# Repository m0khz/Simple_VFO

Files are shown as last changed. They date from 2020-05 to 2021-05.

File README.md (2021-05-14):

# Simple_VFO
Simple VFO using Si5351 &amp; custom hardware.

A comprehensive video build of this project is available here:

https://youtu.be/oWSVf3w8YGg

The 2.2" tft module uses the ILI9341 driver there are different versions out there and the pinout changes,

 *                            - the boards have been designed for this type:
 *                            - https://www.elektor.com/2-2-spi-tft-display-module-240x320 
 *                            - I bought mine from eBay

The Teensy 3.2 module available from https://www.pjrc.com/store/teensy32.html 

 *                            - I bought mine from eBay

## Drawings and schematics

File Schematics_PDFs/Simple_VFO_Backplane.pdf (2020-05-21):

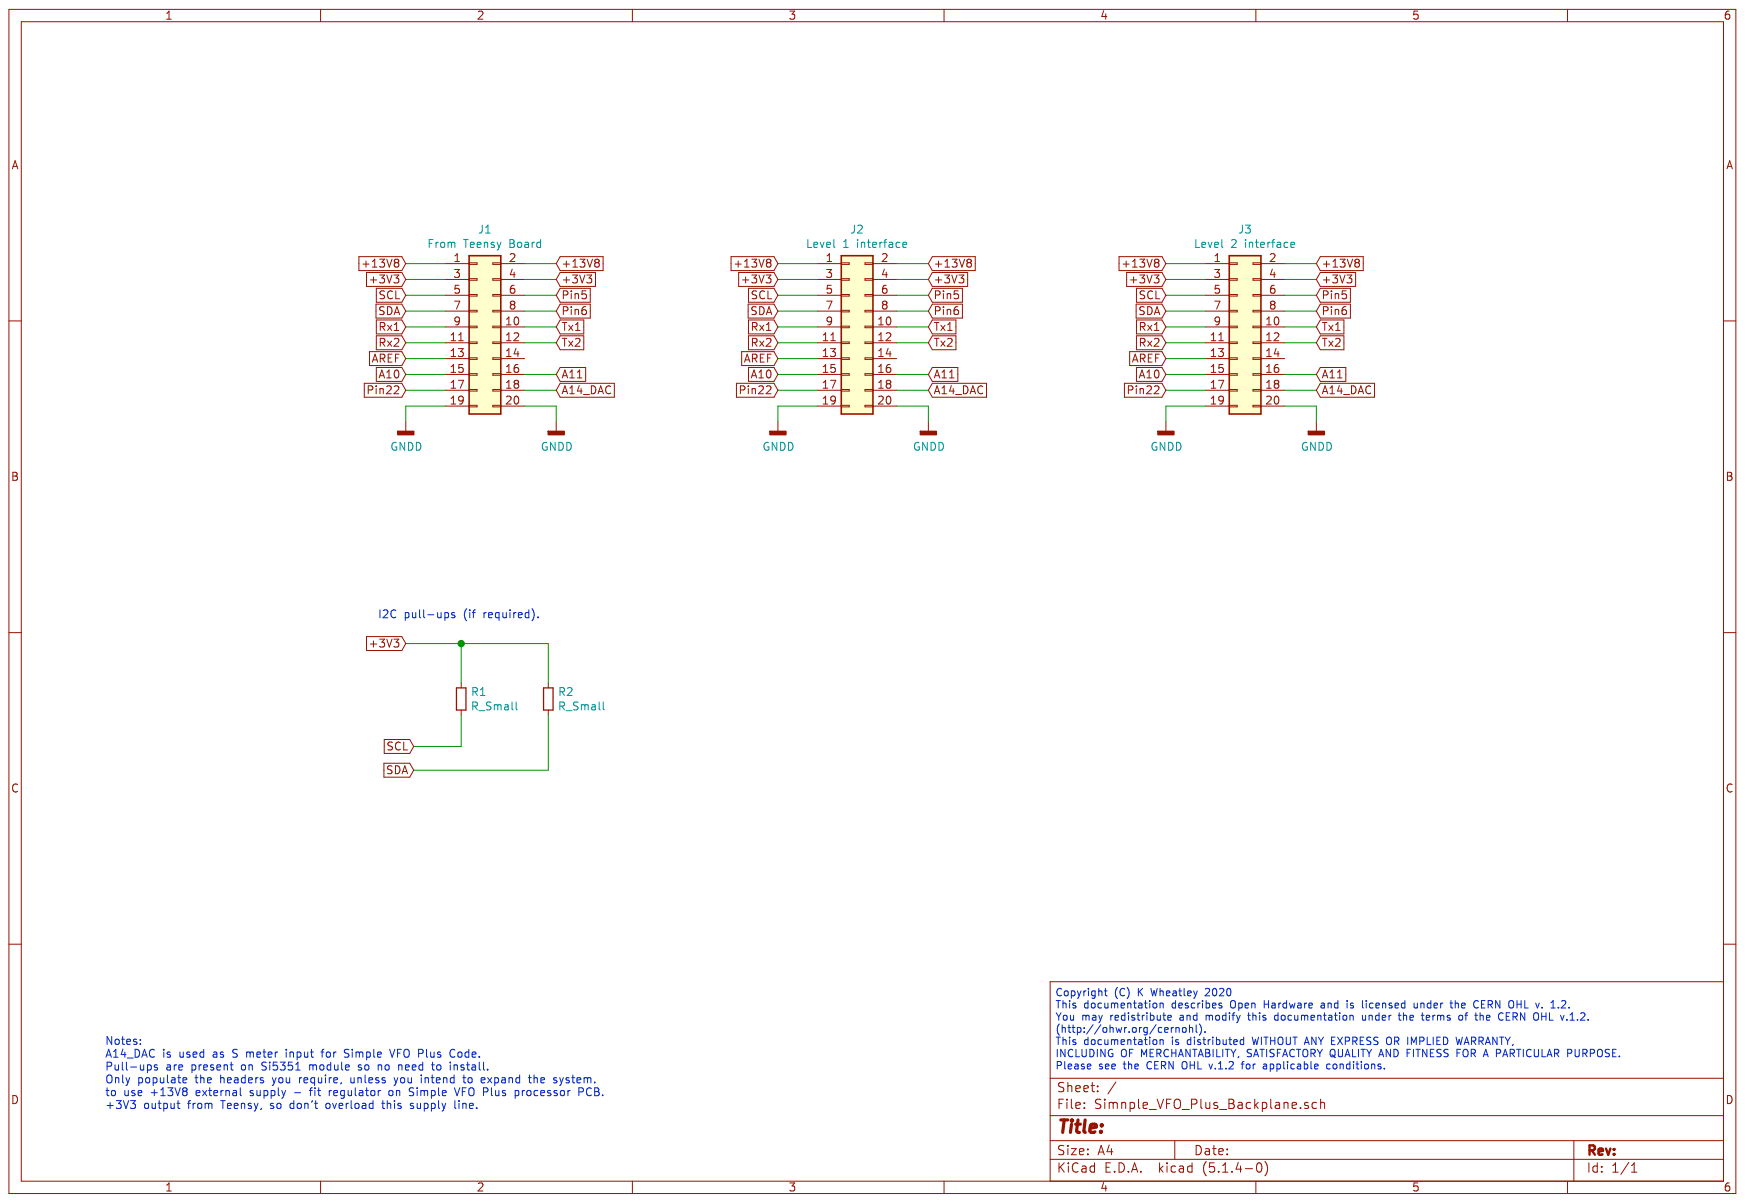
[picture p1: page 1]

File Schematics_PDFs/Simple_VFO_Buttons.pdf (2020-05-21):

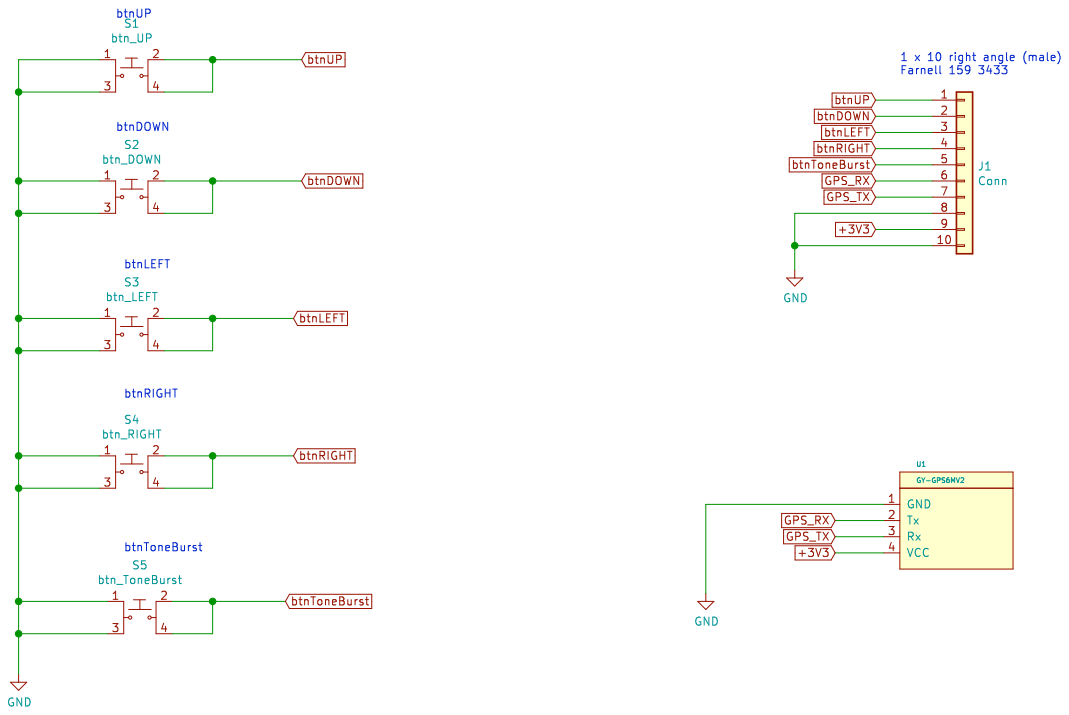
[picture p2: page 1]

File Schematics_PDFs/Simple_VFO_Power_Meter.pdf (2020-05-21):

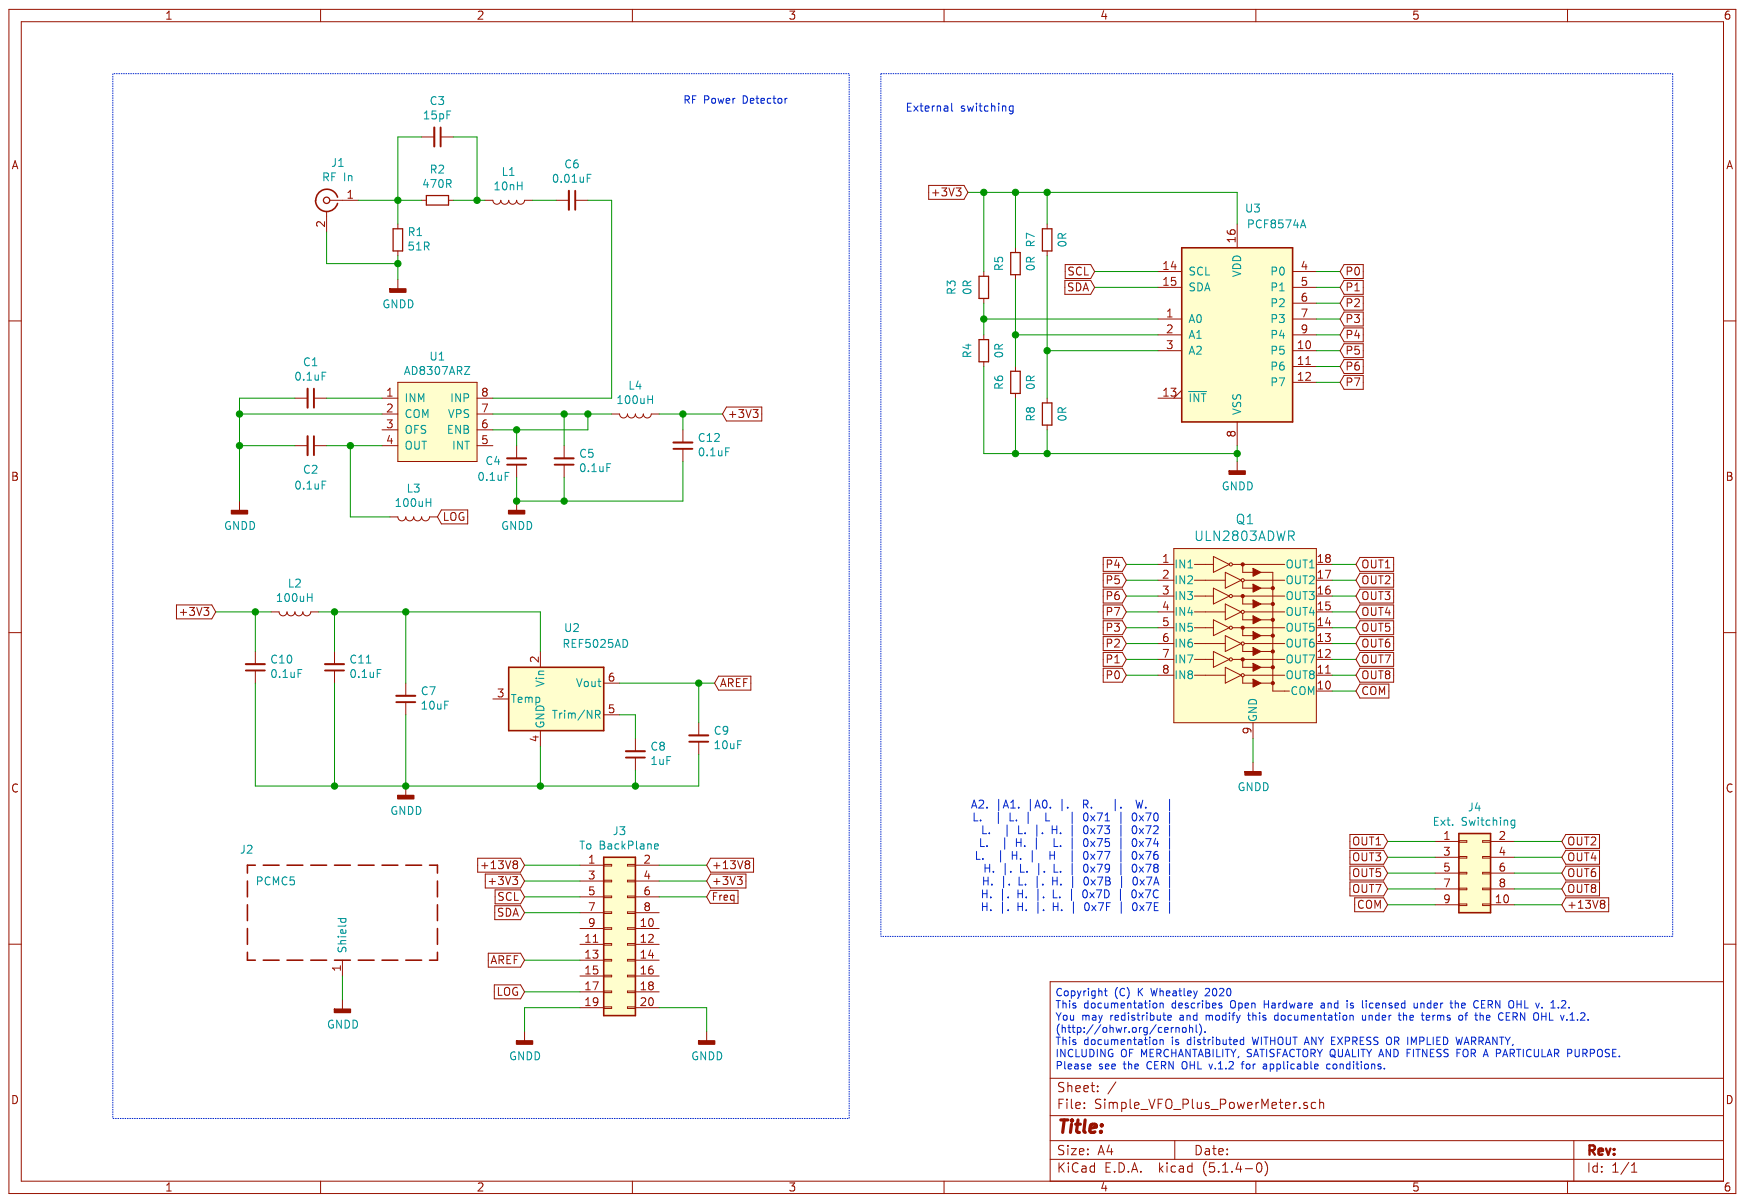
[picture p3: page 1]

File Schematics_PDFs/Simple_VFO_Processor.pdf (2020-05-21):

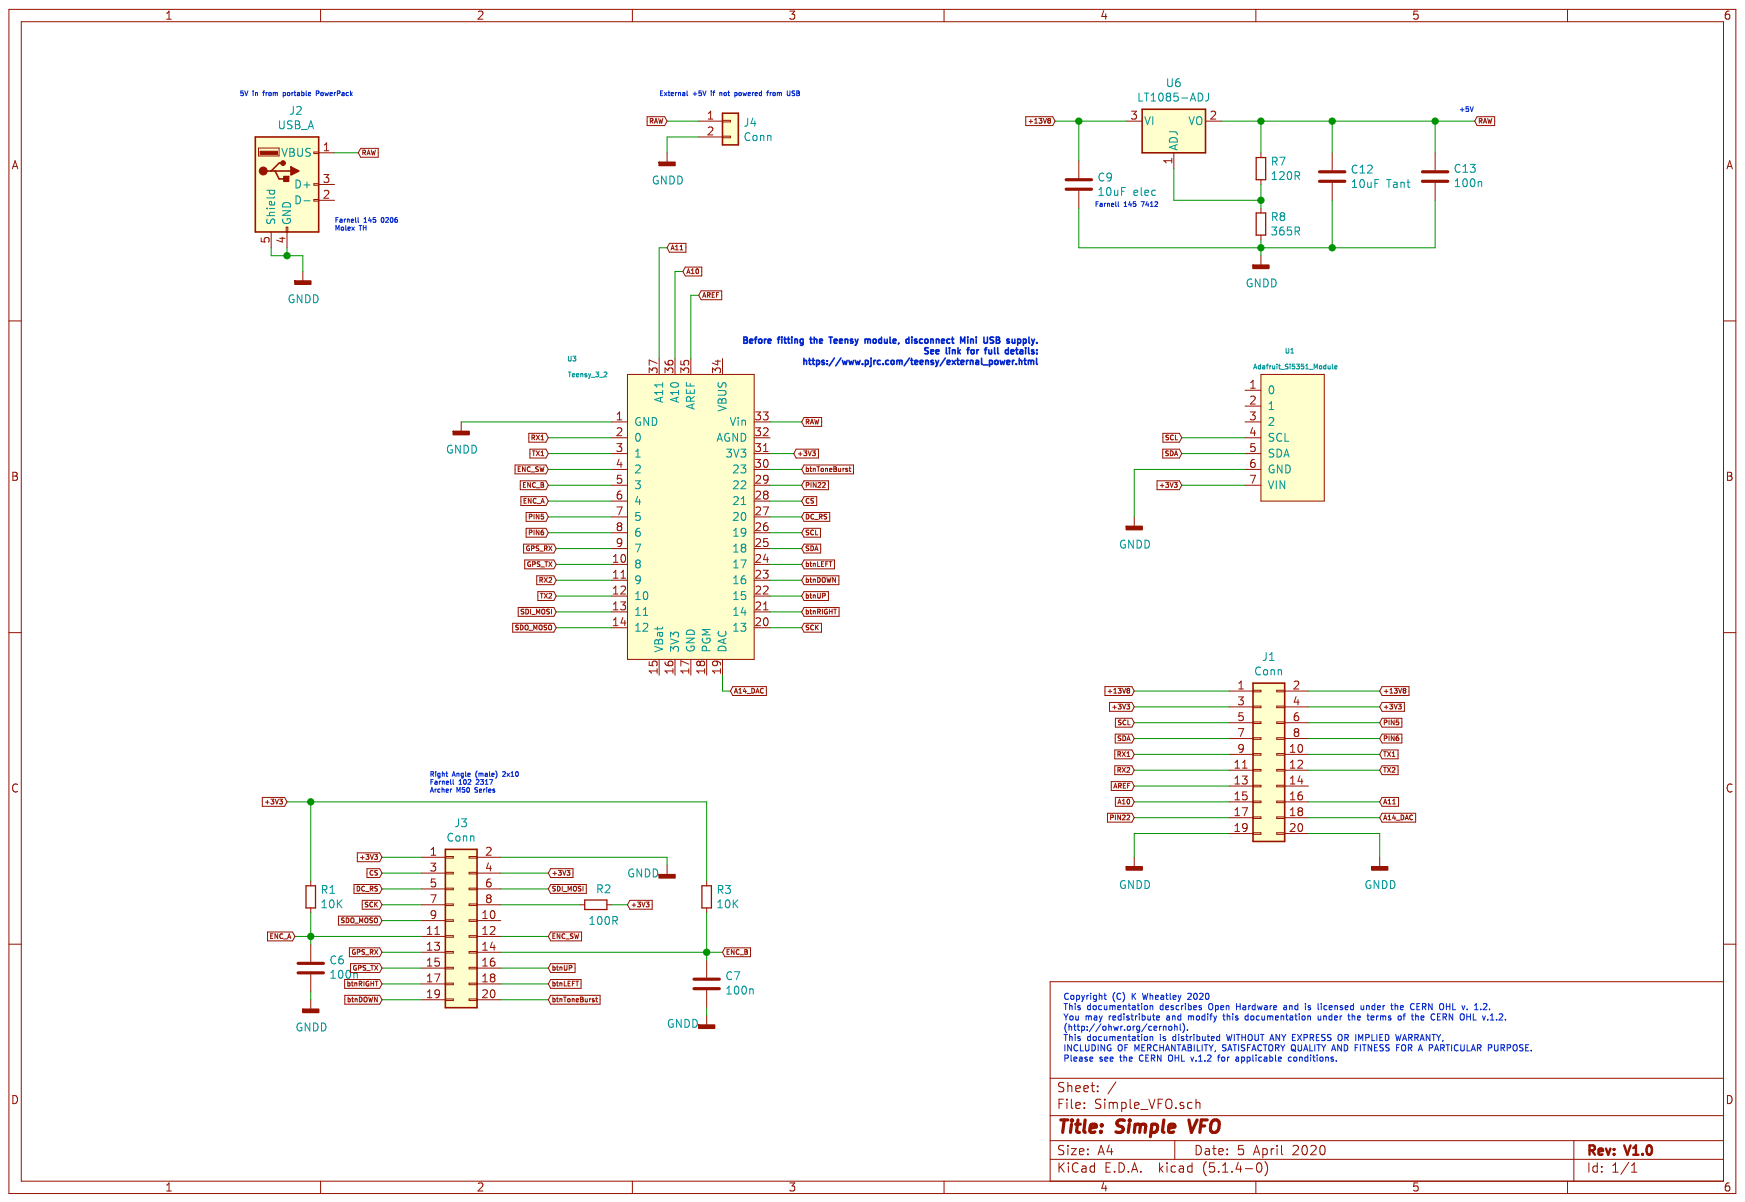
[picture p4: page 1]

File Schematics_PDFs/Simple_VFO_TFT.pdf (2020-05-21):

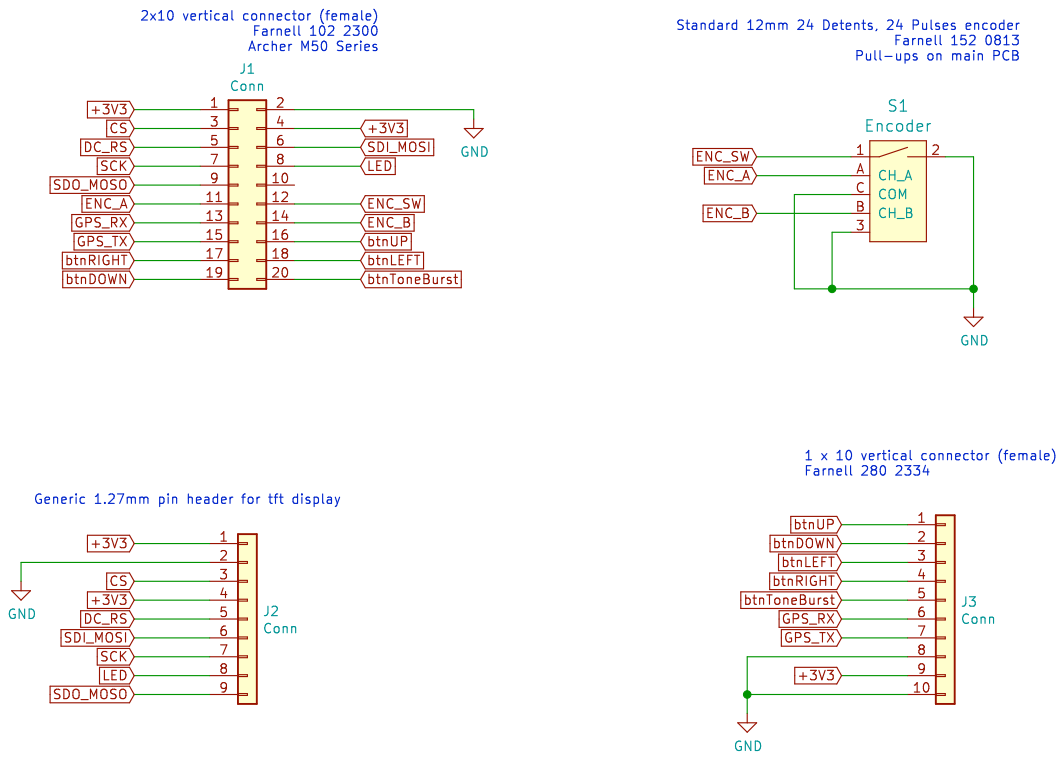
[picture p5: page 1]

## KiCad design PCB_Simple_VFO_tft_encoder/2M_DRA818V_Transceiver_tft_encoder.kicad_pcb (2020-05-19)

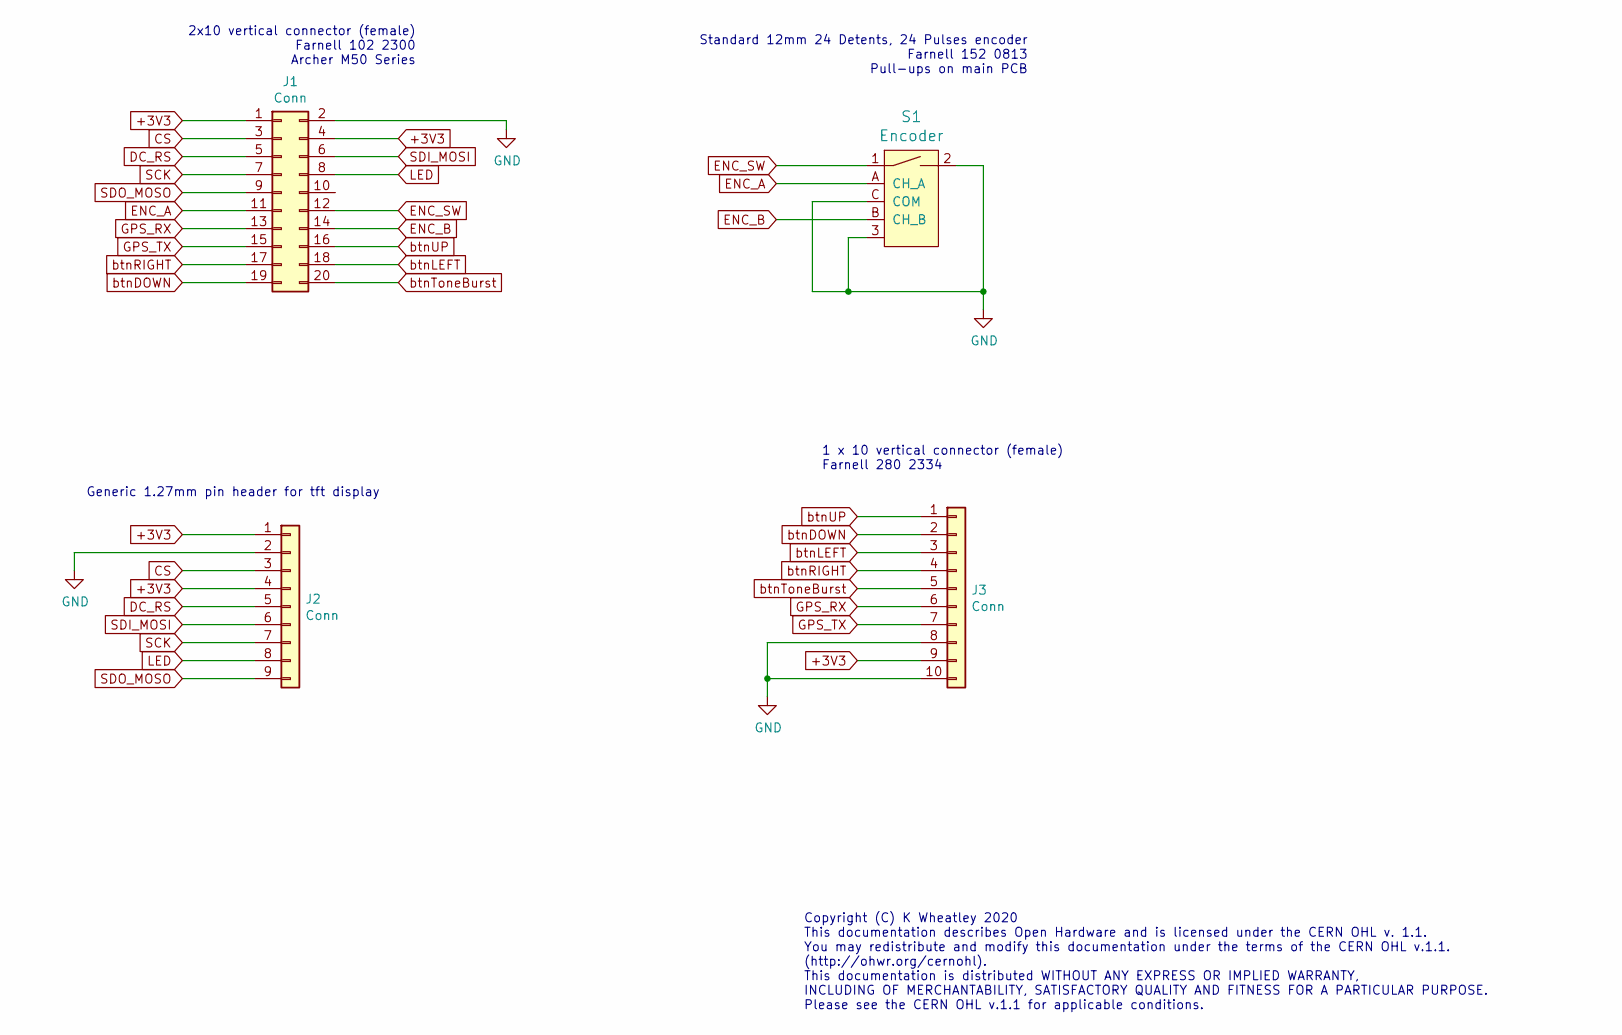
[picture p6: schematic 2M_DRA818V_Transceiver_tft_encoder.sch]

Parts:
J1: Conn; PinHeader_2x10_P2.54mm_Vertical
J2: Conn; PinHeader_1x09_P2.54mm_Vertical
J3: Conn; PinHeader_1x10_P2.54mm_Vertical
S1: Encoder; Rotary_Encoder_Switched_PEC11R; MPN PEC11R-4215F-S0024; Digi-Key_PN PEC11R-4215F-S0024-ND

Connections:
+3V3: J1.1, J1.4, J2.1, J2.4, J3.9
CS: J1.3, J2.3
DC_RS: J1.5, J2.5
ENC_A: J1.11, S1.A (CH_A)
ENC_B: J1.14, S1.B (CH_B)
ENC_SW: J1.12, S1.1
GND: J1.2, J2.2, J3.8, J3.10, S1.2, S1.3, S1.C (COM)
GPS_RX: J1.13, J3.6
GPS_TX: J1.15, J3.7
LED: J1.8, J2.8
SCK: J1.7, J2.7
SDI_MOSI: J1.6, J2.6
SDO_MOSO: J1.9, J2.9
btnDOWN: J1.19, J3.2
btnLEFT: J1.18, J3.3
btnRIGHT: J1.17, J3.4
btnToneBurst: J1.20, J3.5
btnUP: J1.16, J3.1

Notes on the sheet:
2x10 vertical connector (female) Farnell 102 2300 Archer M50 Series
Generic 1.27mm pin header for tft display
Standard 12mm 24 Detents, 24 Pulses encoder Farnell 152 0813 Pull-ups on main PCB
Copyright (C) K Wheatley 2020 This documentation describes Open Hardware and is licensed under the CERN OHL v. 1.1. You may redistribute and modify this documentation under the terms of the CERN OHL v.1.1. (http://ohwr.org/cernohl). This documentation is distributed WITHOUT ANY EXPRESS OR IMPLIED W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
1 x 10 vertical connector (female) Farnell 280 2334

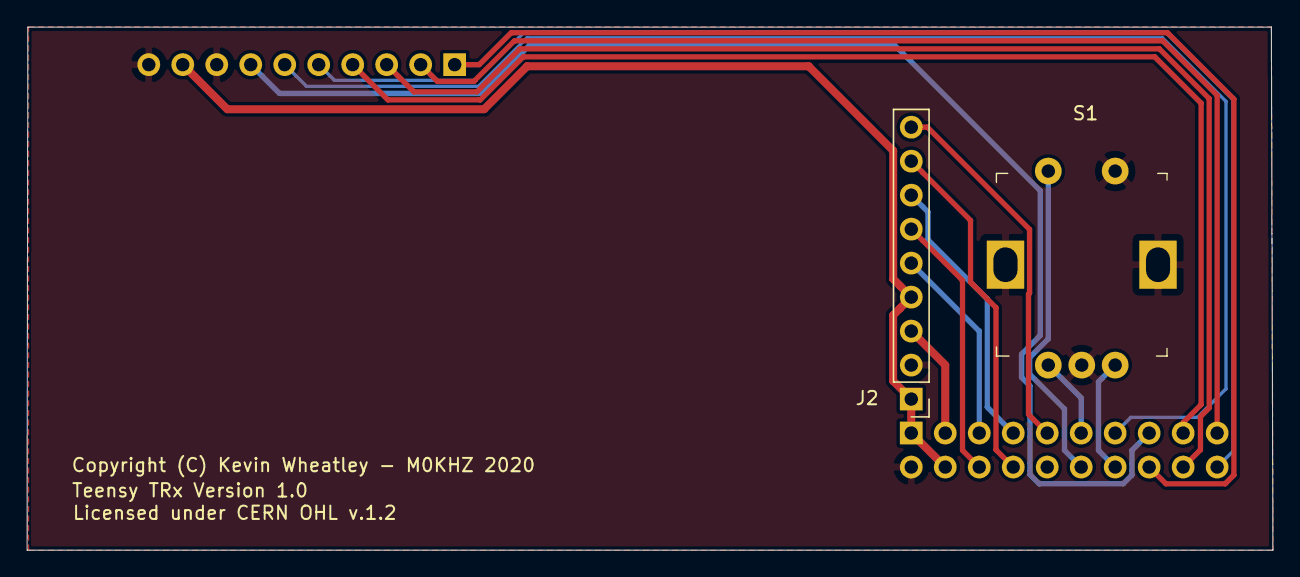
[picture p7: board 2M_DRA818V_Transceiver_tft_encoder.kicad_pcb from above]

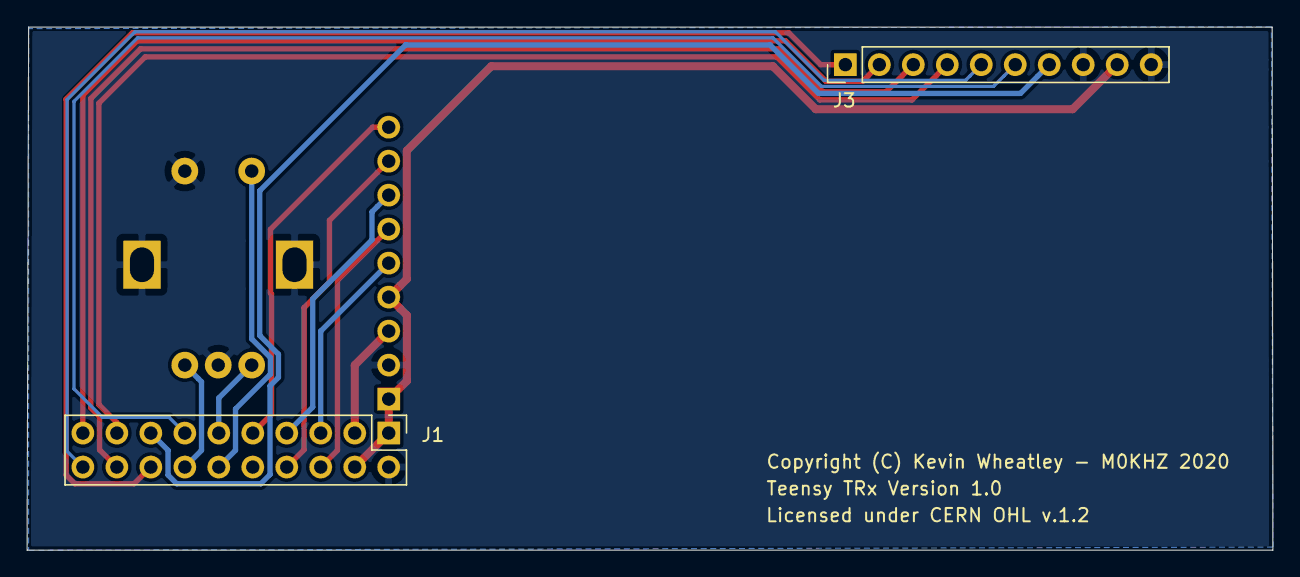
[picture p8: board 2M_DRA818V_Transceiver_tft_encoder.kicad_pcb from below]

Board: 2 copper layers, 93.1 x 39.1 mm, 4 parts (2 on the bottom side), 18 nets.

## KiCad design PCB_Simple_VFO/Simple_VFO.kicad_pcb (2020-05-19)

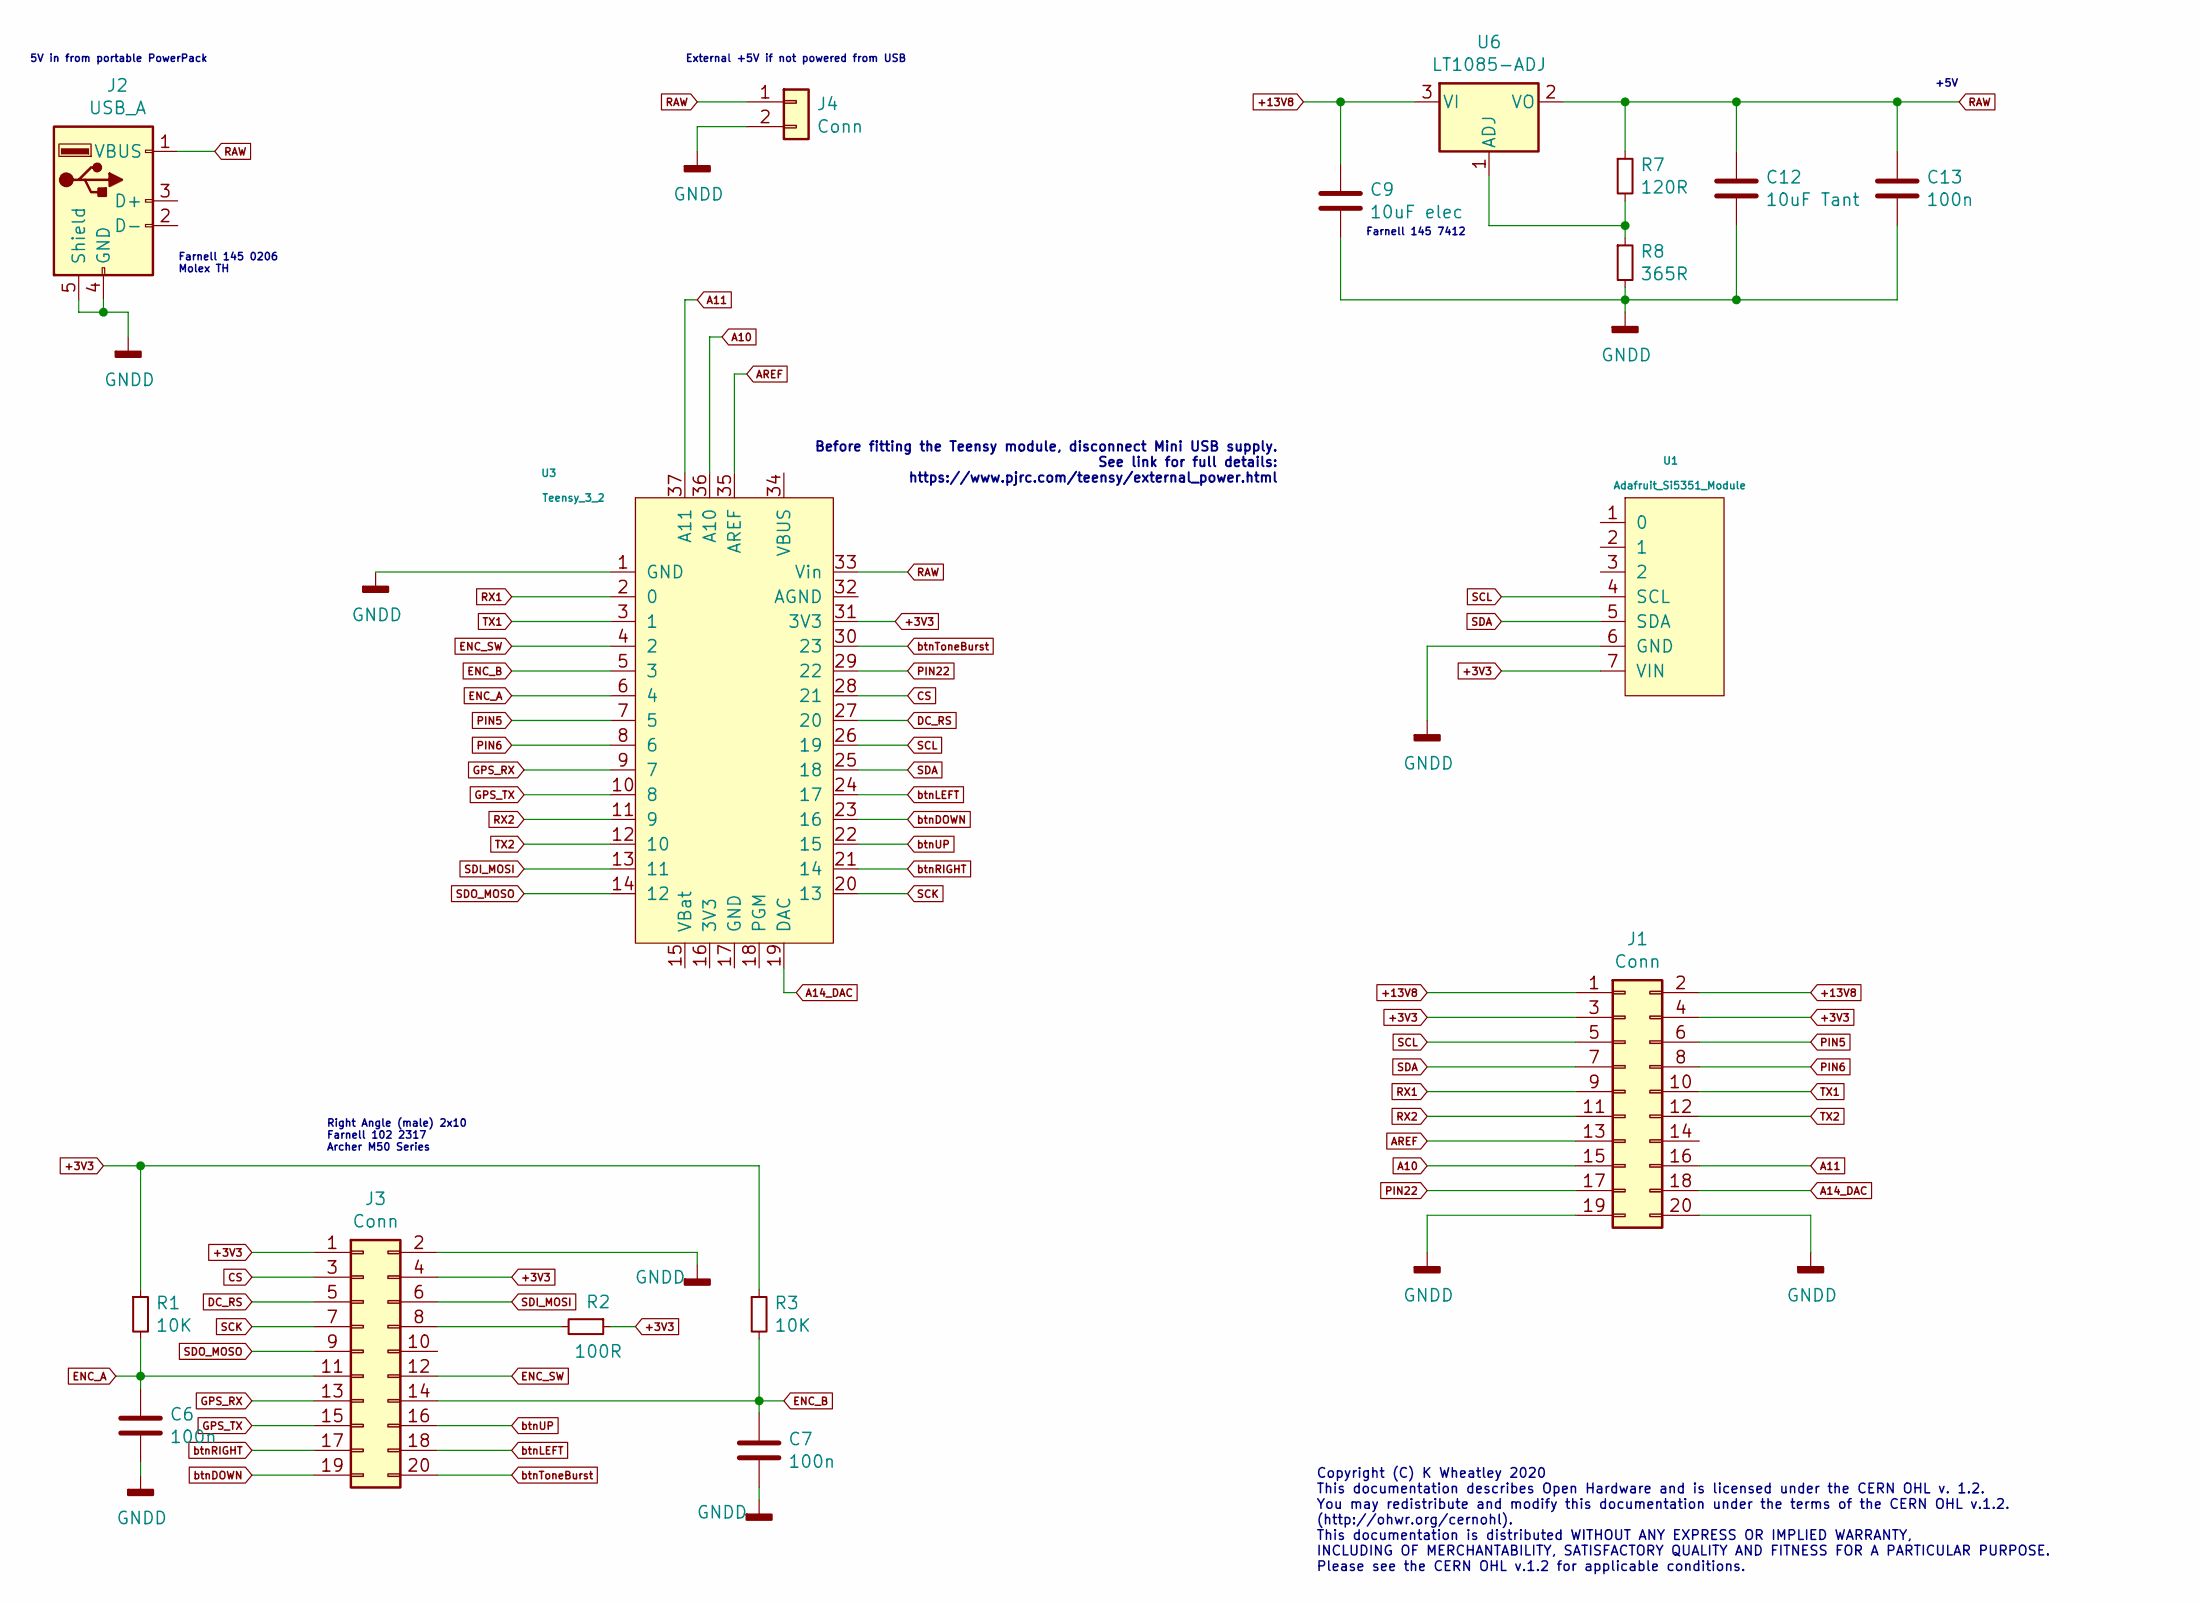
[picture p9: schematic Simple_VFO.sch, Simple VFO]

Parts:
C6, C7, C13: 100n; C_0603_1608Metric_Pad1.05x0.95mm_HandSolder
C9: 10uF elec; CP_EIA-3216-12_Kemet-S_Pad1.58x1.35mm_HandSolder
C12: 10uF Tant; CP_EIA-3216-12_Kemet-S_Pad1.58x1.35mm_HandSolder
J1, J3: Conn; PinHeader_2x10_P2.54mm_Horizontal
J2: USB_A; USB_A_Stewart_SS-52100-001_Horizontal
J4: Conn; PinHeader_1x02_P2.54mm_Vertical
R1, R3: 10K; C_0603_1608Metric_Pad1.05x0.95mm_HandSolder
R2: 100R; C_0603_1608Metric_Pad1.05x0.95mm_HandSolder
R7: 120R; C_0603_1608Metric_Pad1.05x0.95mm_HandSolder
R8: 365R; C_0603_1608Metric_Pad1.05x0.95mm_HandSolder
U1: Adafruit_Si5351_Module
U3: Teensy_3_2
U6: LT1085-ADJ; TO-263-3_TabPin2

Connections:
+3V3: J1.3, J1.4, J3.1, J3.4, R1.1, R2.1, R3.1, U1.7 (VIN), U3.31 (3V3)
+13V8: C9.1, J1.1, J1.2, U6.3 (VI)
A10: J1.15, U3.36 (A10)
A11: J1.16, U3.37 (A11)
A14_DAC: J1.18, U3.19 (DAC)
AREF: J1.13, U3.35 (AREF)
CS: J3.3, U3.28 (21)
DC_RS: J3.5, U3.27 (20)
ENC_A: C6.2, J3.11, R1.2, U3.6 (4)
ENC_B: C7.2, J3.14, R3.2, U3.5 (3)
ENC_SW: J3.12, U3.4 (2)
GNDD: C6.1, C7.1, C9.2, C12.2, C13.1, J1.19, J1.20, J2.4 (GND), J2.5 (Shield), J3.2, J4.2, R8.2, U1.6 (GND), U3.1 (GND)
GPS_RX: J3.13, U3.9 (7)
GPS_TX: J3.15, U3.10 (8)
unnamed: J3.8, R2.2
unnamed: R7.2, R8.1, U6.1 (ADJ)
PIN5: J1.6, U3.7 (5)
PIN6: J1.8, U3.8 (6)
PIN22: J1.17, U3.29 (22)
RAW: C12.1, C13.2, J2.1 (VBUS), J4.1, R7.1, U3.33 (Vin), U6.2 (VO)
RX1: J1.9, U3.2 (0)
RX2: J1.11, U3.11 (9)
SCK: J3.7, U3.20 (13)
SCL: J1.5, U1.4 (SCL), U3.26 (19)
SDA: J1.7, U1.5 (SDA), U3.25 (18)
SDI_MOSI: J3.6, U3.13 (11)
SDO_MOSO: J3.9, U3.14 (12)
TX1: J1.10, U3.3 (1)
TX2: J1.12, U3.12 (10)
btnDOWN: J3.19, U3.23 (16)
btnLEFT: J3.18, U3.24 (17)
btnRIGHT: J3.17, U3.21 (14)
btnToneBurst: J3.20, U3.30 (23)
btnUP: J3.16, U3.22 (15)

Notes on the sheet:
5V in from portable PowerPack
Right Angle (male) 2x10 Farnell 102 2317 Archer M50 Series
Farnell 145 7412
Farnell 145 0206 Molex TH
Before fitting the Teensy module, disconnect Mini USB supply. See link for full details: https://www.pjrc.com/teensy/external_power.html
Copyright (C) K Wheatley 2020 This documentation describes Open Hardware and is licensed under the CERN OHL v. 1.2. You may redistribute and modify this documentation under the terms of the CERN OHL v.1.2. (http://ohwr.org/cernohl). This documentation is distributed WITHOUT ANY EXPRESS OR IMPLIED W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
External +5V if not powered from USB
+5V

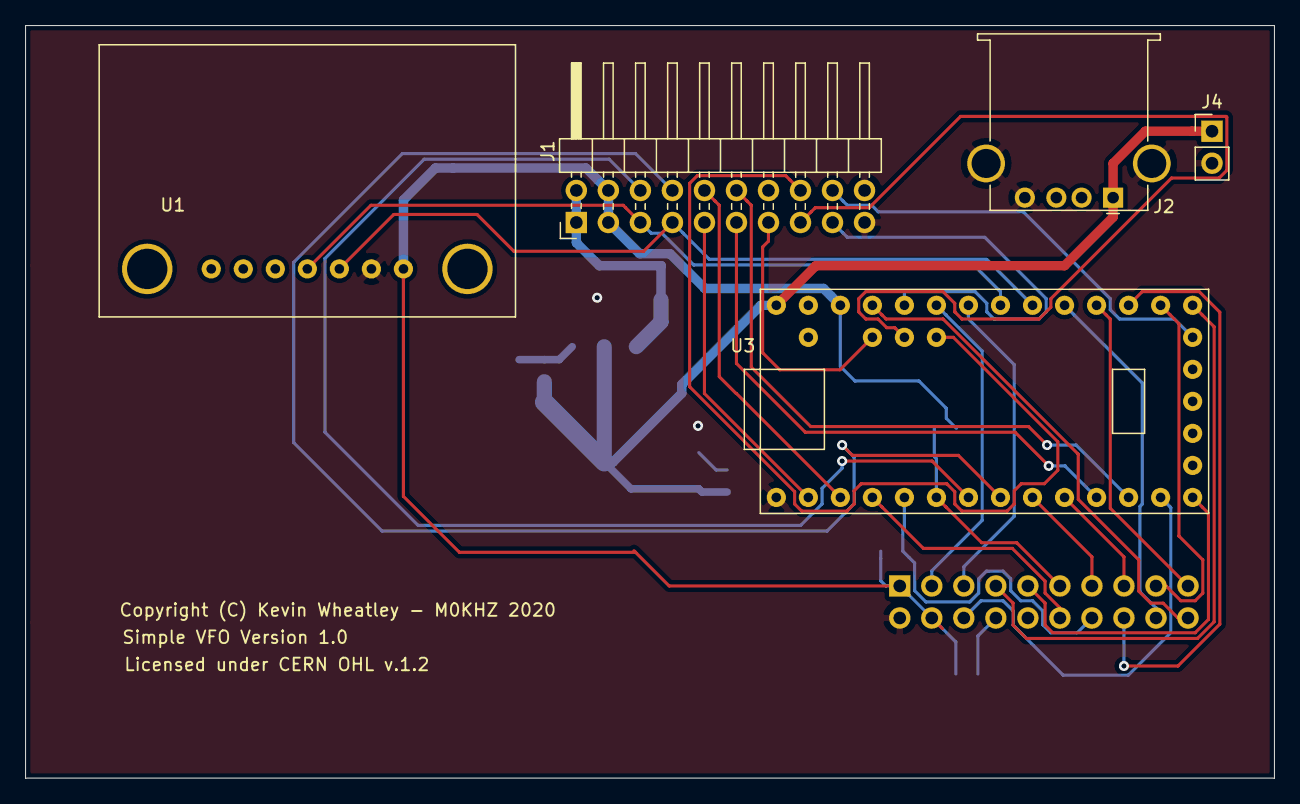
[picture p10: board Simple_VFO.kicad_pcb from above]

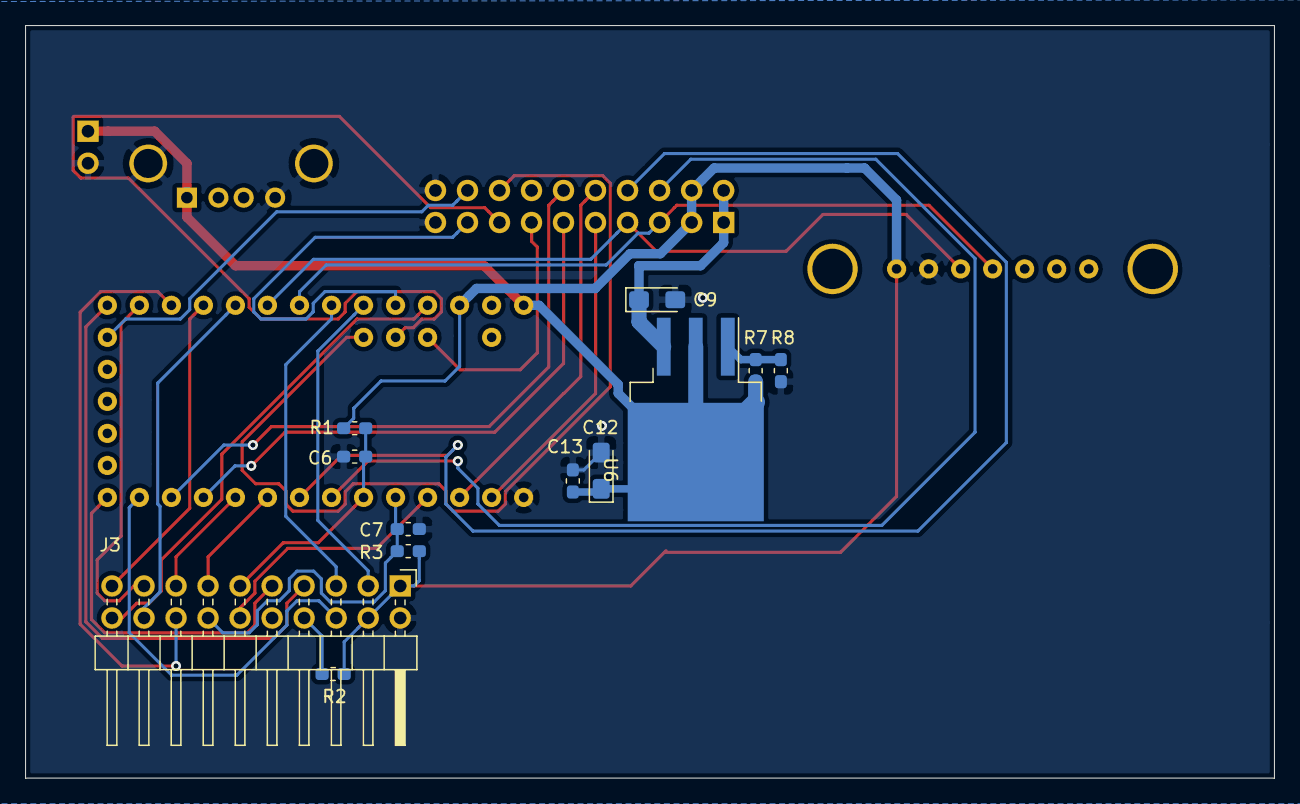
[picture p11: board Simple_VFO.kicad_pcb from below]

Board: 2 copper layers, 99.1 x 59.7 mm, 17 parts (12 on the bottom side), 34 nets.

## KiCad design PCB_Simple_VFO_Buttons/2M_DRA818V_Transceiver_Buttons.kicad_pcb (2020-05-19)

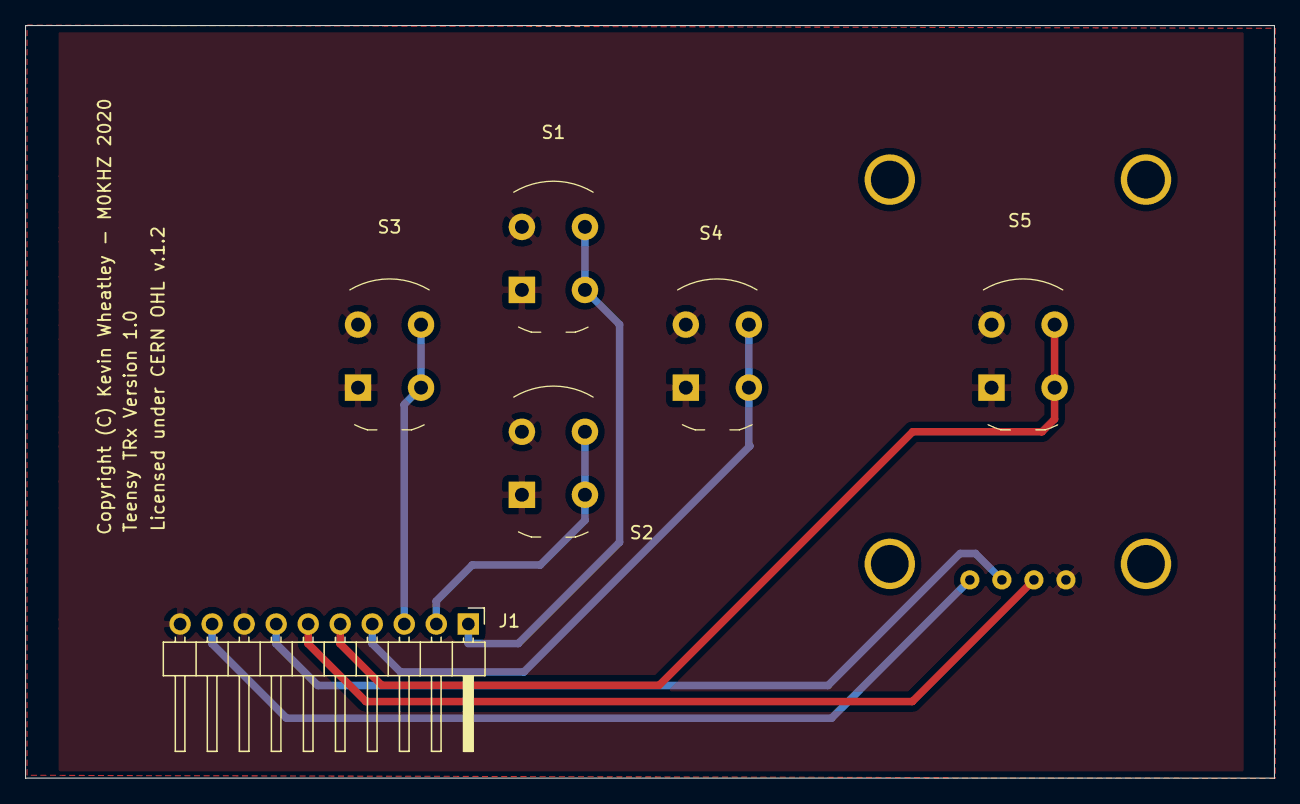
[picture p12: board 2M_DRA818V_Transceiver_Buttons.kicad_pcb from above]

Board: 2 copper layers, 99.1 x 59.7 mm, 7 parts (1 on the bottom side), 9 nets.

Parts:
J1: Conn; PinHeader_1x10_P2.54mm_Horizontal
S1: btn_UP; PushButton_Round_D12mm_THT_KS-01Q-01
S2: btn_DOWN; PushButton_Round_D12mm_THT_KS-01Q-01
S3: btn_LEFT; PushButton_Round_D12mm_THT_KS-01Q-01
S4: btn_RIGHT; PushButton_Round_D12mm_THT_KS-01Q-01
S5: btn_ToneBurst; PushButton_Round_D12mm_THT_KS-01Q-01
U1: GY-GPS6MV2; UBlox_GY-GPS6MV2

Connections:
+3V3: J1.9, U1.4
GND: J1.8, J1.10, S1.1, S1.3, S2.1, S2.3, S3.1, S3.3, S4.1, S4.3, S5.1, S5.3, U1.1
GPS_RX: J1.6, U1.2
GPS_TX: J1.7, U1.3
btnDOWN: J1.2, S2.2, S2.4
btnLEFT: J1.3, S3.2, S3.4
btnRIGHT: J1.4, S4.2, S4.4
btnToneBurst: J1.5, S5.2, S5.4
btnUP: J1.1, S1.2, S1.4

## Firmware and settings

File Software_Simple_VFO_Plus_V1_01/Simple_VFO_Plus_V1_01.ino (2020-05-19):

/*
 * ***********************************************************************************
 * Copyright (c) 2020  M0KHZ - Kevin Wheatley
 * 
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
 * ***********************************************************************************
 * 
 * OK so the initial objectives here are to have a basic VFO operational.
 * Hardware: 
 * 
 *    Si5351 braekout board
 *    Teensy 3.2
 *    2.2 TFT display
 *    
 *    
 * Version 0.001   - 4.04.2020 - Project start basic screen layout (more to add later).
 *                             - Pin assignments
 *                             - 0  - USB Comms / programming / debug 
 *                             - 1  - UBS Comms / programming / debug
 *                             - 2  - IN_ENCODER0_PINSW
 *                             - 3  - IN_ENCODER0_PINA
 *                             - 4  - IN_ENCODER0_PINB
 *                             - 5  - Spare
 *                             - 6  - Spare
 *                             - 7  - Serial3 Rx - possible future use
 *                             - 8  - Serial3 Tx - possible future use
 *                             - 9  - possible future use
 *                             - 10 - possible future use
 *                             - 11 - TFT_SDI/MOSI
 *                             - 12 - TFT_SDO/MOSO
 *                             - 13 - TFT_SCK
 *                             - 14 - Button Right  - Tune_Step_Minus
 *                             - 15 - Button Up     - VFO_AB
 *                             - 16 - Button Down   - VFO_A_B
 *                             - 17 - Button Left   - Tune_Step_Plus
 *                             - 18 - SDA0 - Si5351a breakout module 
 *                             - 19 - SCL0 - Si5351a breakout module 
 *                             - 20 - TFT_DC/RS
 *                             - 21 - TFT_CS
 *                             - 22 - possible future use
 *                             - 23 - Button Enter  - VFO_LOCK
 *                             -    - A14/DAC       - S meter input
 * 
 * Version 0.002   - 5.04.2020 - Started to add encoder code - interrupt driven
 * Version 0.003   - 5.04.2020 - Started to add freq display update code,
 *                             - basic program flow implemented VFO's updated via encoder, switching between VFO's via encoder pushbutton
 * Version 0.004   - 5.04.2020 - TFT display update started.                             
 *                             - added some additional fonts included to start making the display look prity, namely:
 *                             - an aggregation of DroidSansMono and AwesomeF000 fonts.
 *                             - Main and sub VFO's displaying correctly.
 *                             - Splash screen integrated.
 *                             - Sketch uses 190452 bytes (72%) of program storage space. Maximum is 262144 bytes.
 *                             - Global variables use 5516 bytes (8%) of dynamic memory, leaving 60020 bytes for local variables. 
 *                             - Maximum is 65536 bytes.
 * Version 0.005  - 6.04.2020  - Started to implement S meter - test bar working nicely
 *                             - Band limits implemented - limits set in - display_co_ordinates.h
 *                             - Display positioning shuffled about a bit
 * Version 0.006  - 7.04.2020  - Implemented interrupt driven encoder switch. 
 *                             - GPS data added to info screen area
 *                             - Added vanity call display within gps info loop
 * Version 0.007  - 8.04.2020  - Frequency offset code implemented.
 *                             - VFO A/B, VFO A=B and VFO Lock implemented.
 *                             - VFO output implemented on SI5351_CLK0
 *                             - Sketch uses 215808 bytes (82%) of program storage space. Maximum is 262144 bytes.
 *                             - Global variables use 6560 bytes (10%) of dynamic memory, 
 *                             - leaving 58976 bytes for local variables. Maximum is 65536 bytes.
 * Version 0.008  - 12.04.2020 - New method for encoder routines (better transition handling for lookup table).
 *                             - including full and half step, to help with different encoder types.
 *                             - Also freq. multiplier via a new variable : u.tune_multi 
 *                             - Implemented display 'bar' for VFO tuning rate.
 *                             - Implemented VFO Lock indication.
 * Version 0.009  - 14.04.2020 - Implemented S meter on A14, the rainbow_gragh expecting int range between 0 - 273, so
 *                             - after reading the value I'm mapping to the correct range:
 *                             - temp_value = analogRead(A14); 
 *                             - temp_value = map(temp_value,0,1023,0,273);
 *                             - with no input connected and just measureing noise, provides quite a good representation!
 *                             - Changed splash screen image and added call - GQRP - SPRAT.
 * Version 1.0    - 15.04.2020 - Initial release.
 *                             - Sketch uses 218444 bytes (83%) of program storage space. Maximum is 262144 bytes.
 *                             - Global variables use 6652 bytes (10%) of dynamic memory,
 *                             - leaving 58884 bytes for local variables. Maximum is 65536 bytes.
 *                             ************** Started signal generator functionality ******************
 * Version 0.01   - 12.05.2020 - Added a simple signal generator function, encoder push button
 *                             - toggles between VFO & Sig gen modes.
 * Version 0.02   - 13.05.2020 - Added second Si5351 clock output, A=B, AB exchange, frequency multipliers text improvement.
 *                             - Changed splash screen to 'eye test'
 * Version 0.03   - 13.05.2020 - Added disable the global interrupt setting with cli() and reenable with with sei() on encoder 
 *                             - inturrupt routines
 *                             - Added lock to frequency generator mode.
 * Version 0.04   - 13.05.2020 - Added 1Mhz tuning to frequency generation mode
 * Version 1.01   - 14.05.2020 - Project renamed as Simple VFO Plus, for release.
 *                             
 * *********************************************************************************************
 * 
 * Hardware notes:
 *                            - Teensy 3.2 module available from https://www.pjrc.com/store/teensy32.html 
 *                            - I bought mine from eBay
 *                                               
 *                            - tft module uses the ILI9341 driver there are different versions out there and the pinout changes,
 *                            - the boards have been designed for this type:
 *                            - https://www.elektor.com/2-2-spi-tft-display-module-240x320 
 *                            - I bought mine from eBay
 *                            
 *                            - Processor board version 1.1
 *                            - Display board version 1.0
 *                            - Button board version 1.0
 *                        
 *                            - Implement this Si5351 library : https://github.com/etherkit/Si5351Arduino
 *                            - VFO output implemented on SI5351_CLK0
 *                            - Signal generator implemented on Si5351_CLK0 & SI5351_CLK2
 *                            
 *                            
 * *********************************************************************************************
 *                            
 * Development environment:                           
 * 
 *  Teensyduino   version - 1.49-beta1  For instalation details see: https://www.pjrc.com/teensy/td_download.html
 *    
 *                            
 * -------------------- To Do List ----------------
 * 
 *  Implement:
 *  Add files to gitHub
 *  
 *  Future development - needs addition hardware (under development 19.05.2020) developed first.....
 *  Long push on encoder switch then implement power meter.
 *  This Power meter capability will be 'rolled into' the existing code, with the ability to switch between
 *  Simple VFO/Sig gen mode & Power meter modes.
 *  
 *  Note with above hardware and different software loaded it should be possible to use
 *  Farhan VU2ESE's Sweeperino software (after modification to suit this hardware etc.)
 *  
 *  
 */

#define MY_CALLSIGN "GQRP - SPRAT"            // callsign used for display testing

// add the libraries to support the display
#include "SPI.h"
#include "ILI9341_t3.h"
// end of display library requirements

// tft display definitions
#define TFT_DC 20
#define TFT_CS 21
ILI9341_t3 tft = ILI9341_t3(TFT_CS, TFT_DC);

// used for S meter update timing
#include <Metro.h>
// Instantiate a metro object and set the interval to 250 milliseconds (0.25 seconds).
Metro metroSGragh = Metro(200); 

// used for button debounce etc.
#include <Bounce.h>

// add the library for the interrupt handler timer
#include <TimerOne.h>

// use this utility to create new picture content:
// http://www.rinkydinkelectronics.com/_t_doimageconverter565.php
//
#include "image_240_320.c"

// Things to make the display look pretty :)
#include "display_co_ordinates.h"

/*
 *  Left           - increase frequency multiplier
 *  Right          - decrease frequency multiplier
 *  Enter          - Lock VFO
 *  Up             - VFO A=B
 *  Down           - VFO A/B
 *  encoder switch - MODE exchange - VFO or Freq Gen mode
 */

// Button assignments:
#define VFO_AB              15  // VFO A=B i.e A=B or B=A
// Instantiate a Bounce object with a 5 millisecond debounce time
Bounce bouncer_VFO_AB = Bounce(VFO_AB, 50);   // VFO A=B

#define VFO_A_B             16  // VFO A/B Swap active 
// Instantiate a Bounce object with a 5 millisecond debounce time
Bounce bouncer_VFO_A_B = Bounce(VFO_A_B, 50); // VFO A/B

#define Tune_Step_Plus      17   // Tuning step ++ 
// Instantiate a Bounce object with a 5 millisecond debounce time    
Bounce bouncer_Tune_Step_Plus = Bounce(Tune_Step_Plus,50 ); 

#define Tune_Step_Minus     14  // Tuning step --  
// Instantiate a Bounce object with a 5 millisecond debounce time   
Bounce bouncer_Tune_Step_Minus = Bounce(Tune_Step_Minus,50 ); 

#define VFO_LOCK            23  // 
// Instantiate a Bounce object with a 5 millisecond debounce time
Bounce bouncer_VFO_LOCK = Bounce(VFO_LOCK,50 ); 

#define MODE                 2  // switches between simple VFO & simple signal gen modes
// Instantiate a Bounce object with a 5 millisecond debounce time
Bounce bouncer_MODE = Bounce(MODE,50 ); 

// Button functions
#include "Button_functions.h"


// Display drawing / refresh functions
#include "display_functions.h"

// Si5351a update functions
#include <si5351.h>
// Instantiate the VFO Object
Si5351 si5351;
#include "si5351_functions.h"

// Encoder functions
#include "encoder_functions.h"

// vfo_and_band functions
#include "vfo_and_band.h"

// S meter functions
#include "S_meter_functions.h"
#define s_meter A14

// GPS functions
#define gpsSerial Serial3
#include <TinyGPS++.h>
TinyGPSPlus gps; 
#include "gps_functions.h"
// create gps object

// Frequency Generation functions
#include "freq_gen.h"

// ------------- Setup ---------------------------------
void setup() {
  // put your setup code here, to run once:
  // just incase we need some diagnostics
  Serial.begin(9600);
  // and comms to gps module
  gpsSerial.begin(9600);
  
  // Initialise I2C Communications
  Wire.begin();

  // Setup encoder pins with internal pullups enabled.
  pinMode (encoder0PinA,INPUT_PULLUP);
  pinMode (encoder0PinB,INPUT_PULLUP);

  // initialise physical buttons
  pinMode(VFO_AB, INPUT_PULLUP);
  pinMode(VFO_A_B, INPUT_PULLUP);
  pinMode(MODE, INPUT_PULLUP); // swaps between simple VFO & simple sig gen mode
  pinMode(VFO_LOCK, INPUT_PULLUP);
  pinMode(Tune_Step_Plus, INPUT_PULLUP);
  pinMode(Tune_Step_Minus, INPUT_PULLUP);
  
  // init display
  tft.begin();
  tft.setRotation(1); // will need to change this to 1 for panel mounting in case
  tft.fillScreen(ILI9341_BLACK);
  // display welcome message
  splashscreen();

  // small delay before clearing screen
  delay(5000);
  // now clear the display
  tft.fillScreen(ILI9341_BLACK);

  // So for this sort of project, i.e. where the user will expect instant response to a change on the frequency dial,
  // we have chosen to make the encoder routine interrupt driven, so if the interrupt is triggered
  // irrespective of where the main loop is, the interrupt 'handler' is actioned.
  //
  // Two methods are available below, select the one most suitable for your type of encoder, 
  // note some cheap encoders tend to double count, choosing the right interrupt routine below should help.

  // Setup interrupt handling for the encoder half- or full-step
  attachInterrupt(digitalPinToInterrupt(encoder0PinA), MainRotEncFullStep, CHANGE);
  //attachInterrupt(digitalPinToInterrupt(encoder0PinA), MainRotEncHalfStep, CHANGE);

  attachInterrupt(digitalPinToInterrupt(encoder0PinB), MainRotEncFullStep, CHANGE);
  //attachInterrupt(digitalPinToInterrupt(encoder0PinB), MainRotEncHalfStep, CHANGE);
  
  // now setup Si5351 module
  initialise_dds();

   //Load default start frequency
      u.vfo_a = u.vfo_default;
      u.vfo_b = u.vfo_default;

    //Load default sig gen frequency
      u.fg_A_value = u.sig_gen_def_freq;
      u.fg_B_value = u.sig_gen_def_freq;

// Setup S meter
  analogReference(INTERNAL);                   // use internal reference for the ADC  
  pinMode(s_meter, INPUT);   
}
// ------------- End of Setup ---------------------------------


// ------------- Main Loop ------------------------------------
void loop() {
  // put your main code here, to run repeatedly:
  
  // button handler check for action
    switch_bouncer();

  // if flag.mode == 0 then we are in VFO mode
  if(flag.mode==false){
  // redraw display only if "flag.ReDraw_Screen==true" - this stop screen flicker and only changes the display when requested.
    if(flag.ReDraw_Screen==true)
    {
      display_main_screen(); 
      // OK we've drawn the display or redrawn if we requeted it
      
      // draw S meter background
      meter();
   
    }
    // now process any user requests, i.e change of VFO or band etc.
    // this fubction is called on each loop through of code
    vfo_and_band_handler ();   
    
    // So if the encoder has changed the freq_Changed flag will be 'true'
    // So we need to update the display, we do this here
    if(flag.freq_Changed==true)
    {
      // call function to update the VFO
      display_update_vfo();
      // call function to update the Si5351 output
      update_si5351();
      flag.freq_Changed=false;
      flag.vfo_AB_changed = false;
      flag.vfo_A_B_changed = false;
    }
    // update S meter this runs on each loop through of code
    SmeterBarGragh(); 

    // update gps data
    fetchGpsData();

    // update multiplyer bar
    if(flag.freq_multi_bar == true){
      Freq_Multi_Bar ();
      flag.freq_multi_bar = false;
    }
  }
  if(flag.mode == true){
    // set vfo screen redraw flags for when we return to vfo mode
    flag.ReDraw_Screen=true;
    flag.freq_Changed=true; 
    flag.vfo_A_B_changed=true;
    flag.Smeter = false;
    // now clear screen to enable simple signal gen display
   
    // now display fre gen screen
    display_update_freq_gen_bg();
    // if freq changed
    if(flag.fg_freq_Changed==true){
      // now set Si5351 output
      update_si5351();
    }
    display_update_freq_gen();
    
    display_CLK0_CLK2_Txt ();

    // update multiplyer bar
    if(flag.freq_multi_bar == true){
      Freq_Multi_Bar ();
      flag.freq_multi_bar = false;
    }
  }
} 
// ------------- End of Main Loop ---------------------------------
// ------------- End of file --------------------------------------

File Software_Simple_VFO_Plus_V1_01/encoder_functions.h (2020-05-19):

 /*
 * ***********************************************************************************
 * Copyright (c) 2020  M0KHZ - Kevin Wheatley
 * 
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
 * ***********************************************************************************
*/


// define encoder pins
// So this project has one encoder so we'll call this encoder0, hence the following pin definitions
#define encoder0PinA  3
#define encoder0PinB  4
#define encoder0PinSW 2

// ******** Encoder routines ****************************************************************************
volatile int encState = 0;

const uint8_t encTableHalfStep[6][4] =
{
    {0x3, 0x2, 0x1, 0x0},
    {0x23, 0x0, 0x1, 0x0},
    {0x13, 0x2, 0x0, 0x0},
    {0x3, 0x5, 0x4, 0x0},
    {0x3, 0x3, 0x4, 0x10},
    {0x3, 0x5, 0x3, 0x20},
};

const uint8_t encTableFullStep[7][4] =
{
    {0x0, 0x2, 0x4,  0x0},
    {0x3, 0x0, 0x1, 0x10},
    {0x3, 0x2, 0x0,  0x0},
    {0x3, 0x2, 0x1,  0x0},
    {0x6, 0x0, 0x4,  0x0},
    {0x6, 0x5, 0x0, 0x20},
    {0x6, 0x5, 0x4,  0x0},
};

void MainRotEncHalfStep()
{
  // disable the global interrupt setting with cli()
  cli();
  if(flag.mode == false){
    
    if(flag.vfo_lock==false){
      if(flag.vfo_A_active == true){
        encState = encTableHalfStep[encState & 0xF][(digitalRead(encoder0PinB) << 1) | digitalRead(encoder0PinA)];

        int result = encState & 0x30;

        //if (result)
        // SerialUSB.println(result == 0x20 ? "Left" : "Right");  // 0x20 = Left, 0x10 = Right
        int temp;
        if (result){
        //SerialUSB.println(result == 0x20 ? "Left" : "Right");  // 0x20 = Left, 0x10 = Right
        
          if(result == 0x10){
            temp = 1;
          }
          if(result == 0x20){
            temp = -1;
          }
// -------------- now for frequency multipliers

          if((u.tune_multi)==1){
              u.vfo_a += temp;
          }
          if((u.tune_multi)==2){
              u.vfo_a += (temp * 10);
          }
          if((u.tune_multi)==3){
              u.vfo_a += (temp * 100);
          }
          if((u.tune_multi)==4){
              u.vfo_a += (temp * 1000);
          }
          if((u.tune_multi)==5){
              u.vfo_a += (temp * 10000);
          }
          if((u.tune_multi)==6){
              u.vfo_a += (temp * 100000);
          }
  // --------------- end of frequency multipliers 
     
          flag.freq_Changed=true;
        }
      }

        if(flag.vfo_B_active == true){
        encState = encTableHalfStep[encState & 0xF][(digitalRead(encoder0PinB) << 1) | digitalRead(encoder0PinA)];

        int result = encState & 0x30;

        //if (result)
        // SerialUSB.println(result == 0x20 ? "Left" : "Right");  // 0x20 = Left, 0x10 = Right
        int temp;
        if (result){
          //SerialUSB.println(result == 0x20 ? "Left" : "Right");  // 0x20 = Left, 0x10 = Right
        
          if(result == 0x10){
            temp = 1;
          }
          if(result == 0x20){
            temp = -1;
          }
// -------------- now for frequency multipliers

          if((u.tune_multi)==1){
              u.vfo_b += temp;
          }
          if((u.tune_multi)==2){
              u.vfo_b += (temp * 10);
          }
          if((u.tune_multi)==3){
              u.vfo_b += (temp * 100);
          }
          if((u.tune_multi)==4){
              u.vfo_b += (temp * 1000);
          }
          if((u.tune_multi)==5){
              u.vfo_b += (temp * 10000);
          }
          if((u.tune_multi)==6){
              u.vfo_b += (temp * 100000);
          }
// --------------- end of frequency multipliers 
     
          flag.freq_Changed=true;
        }
      }   
    }
  }
  if(flag.mode == true) { // were're in frequency generation mode so update accordingly

     //fg_tune_multi
    
   }
   // re-enable the global interrupt setting with sei()
   sei();
}

void MainRotEncFullStep()
{
  // disable the global interrupt setting with cli()
  cli();
  if(flag.mode == false){
    if(flag.vfo_lock==false){
      if(flag.vfo_A_active == true){
        encState = encTableFullStep[encState & 0xF][(digitalRead(encoder0PinB) << 1) | digitalRead(encoder0PinA)];

        int result = encState & 0x30;

        //if (result)
        // SerialUSB.println(result == 0x20 ? "Left" : "Right");  // 0x20 = Left, 0x10 = Right
        int temp;
        if (result){
          //SerialUSB.println(result == 0x20 ? "Left" : "Right");  // 0x20 = Left, 0x10 = Right
        
          if(result == 0x10){
            temp = 1;
          }
          if(result == 0x20){
            temp = -1;
          }
// -------------- now for frequency multipliers

          if((u.tune_multi)==1){
              u.vfo_a += temp;
          }
          if((u.tune_multi)==2){
              u.vfo_a += (temp * 10);
          }
          if((u.tune_multi)==3){
              u.vfo_a += (temp * 100);
          }
          if((u.tune_multi)==4){
              u.vfo_a += (temp * 1000);
          }
          if((u.tune_multi)==5){
              u.vfo_a += (temp * 10000);
          }
          if((u.tune_multi)==6){
              u.vfo_a += (temp * 100000);
          }
// --------------- end of frequency multipliers 
     
          flag.freq_Changed=true;
        }
      }

        if(flag.vfo_B_active == true){
        encState = encTableFullStep[encState & 0xF][(digitalRead(encoder0PinB) << 1) | digitalRead(encoder0PinA)];

        int result = encState & 0x30;

        //if (result)
        // SerialUSB.println(result == 0x20 ? "Left" : "Right");  // 0x20 = Left, 0x10 = Right
        int temp;
        if (result){
          //SerialUSB.println(result == 0x20 ? "Left" : "Right");  // 0x20 = Left, 0x10 = Right
        
          if(result == 0x10){
            temp = 1;
          }
          if(result == 0x20){
            temp = -1;
          }
// -------------- now for frequency multipliers

          if((u.tune_multi)==1){
              u.vfo_b += temp;
          }
          if((u.tune_multi)==2){
              u.vfo_b += (temp * 10);
          }
          if((u.tune_multi)==3){
              u.vfo_b += (temp * 100);
          }
          if((u.tune_multi)==4){
              u.vfo_b += (temp * 1000);
          }
          if((u.tune_multi)==5){
              u.vfo_b += (temp * 10000);
          }
          if((u.tune_multi)==6){
              u.vfo_b += (temp * 100000);
          }
// --------------- end of frequency multipliers 
     
          flag.freq_Changed=true;
        }
      }   
    }
  }

   if(flag.mode == true) { // were're in frequency generation mode so update accordingly

    if(flag.fg_lock==false){
      
      if(flag.fg_A_active == true){
        encState = encTableFullStep[encState & 0xF][(digitalRead(encoder0PinB) << 1) | digitalRead(encoder0PinA)];

        int result = encState & 0x30;
        int temp;
        if (result){
        
          if(result == 0x10){
            temp = 1;
          }
          if(result == 0x20){
            temp = -1;
          }
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

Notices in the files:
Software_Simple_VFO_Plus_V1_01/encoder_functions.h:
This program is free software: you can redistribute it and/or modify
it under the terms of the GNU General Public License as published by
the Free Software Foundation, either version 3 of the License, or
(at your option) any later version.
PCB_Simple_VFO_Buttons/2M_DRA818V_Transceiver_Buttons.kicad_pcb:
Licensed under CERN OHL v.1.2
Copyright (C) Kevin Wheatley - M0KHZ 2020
